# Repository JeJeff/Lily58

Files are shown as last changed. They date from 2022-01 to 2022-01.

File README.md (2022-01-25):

# Lily58
Lily58 is 6*4+4keys column-staggered split keyboard.
Lily58Lite-Pic

## [Document Site Here](https://kata0510.github.io/Lily58-Document/)

# Type

- Lily58 Pro
  - [PCB Data](https://github.com/kata0510/Lily58/tree/master/Pro/PCB)
  - [BuildGuide JP](https://kata0510.github.io/Lily58-Document/Lily58_Pro.html)
  - [BuildGuide EN](https://kata0510.github.io/Lily58-Document/Lily58_Pro_BG_ENG.html)
  - [Shop(Yushakobo)](https://yushakobo.jp/shop/lily58-pro/)
- Lily58 Lite Rev2
  - [BuildGuide(YouTube)](https://www.youtube.com/watch?v=t6HLQvqlsVM)
  - [BuildInfo](https://kata0510.github.io/Lily58-Document/Lily58_Lite_Rev2.html)
  - [Shop(BOOTH)](https://booth.pm/ja/items/1963895)
  - [Shop(Yushakobo)](https://yushakobo.jp/shop/consign_lily58-lite-rev2/)
- Lily58(Old)
  - [PCB Data](https://github.com/kata0510/Lily58/tree/master/pcb)
  - [BuildGuide](https://kata0510.github.io/Lily58-Document/Lily58_BG.html)
- Lily58 Lite Rev1(Old)
  - [PCB Data](https://github.com/kata0510/Lily58/tree/master/pcb)
  - [BuildGuide](https://kata0510.github.io/Lily58-Document/Lily58_Lite_BG.html)

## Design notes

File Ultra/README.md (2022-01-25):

# Lily58 Ultra
Lily58 is 6*4+4keys column-staggered split keyboard.

This fork adds the Lily58 Ultra.  This has through-hole diodes only, and adds MX hotswap sockets, per-key and backlight LEDs, and optional rotary encoder support (replacing one of the thumb keys).  The LED support means it no longer supports choc switches.

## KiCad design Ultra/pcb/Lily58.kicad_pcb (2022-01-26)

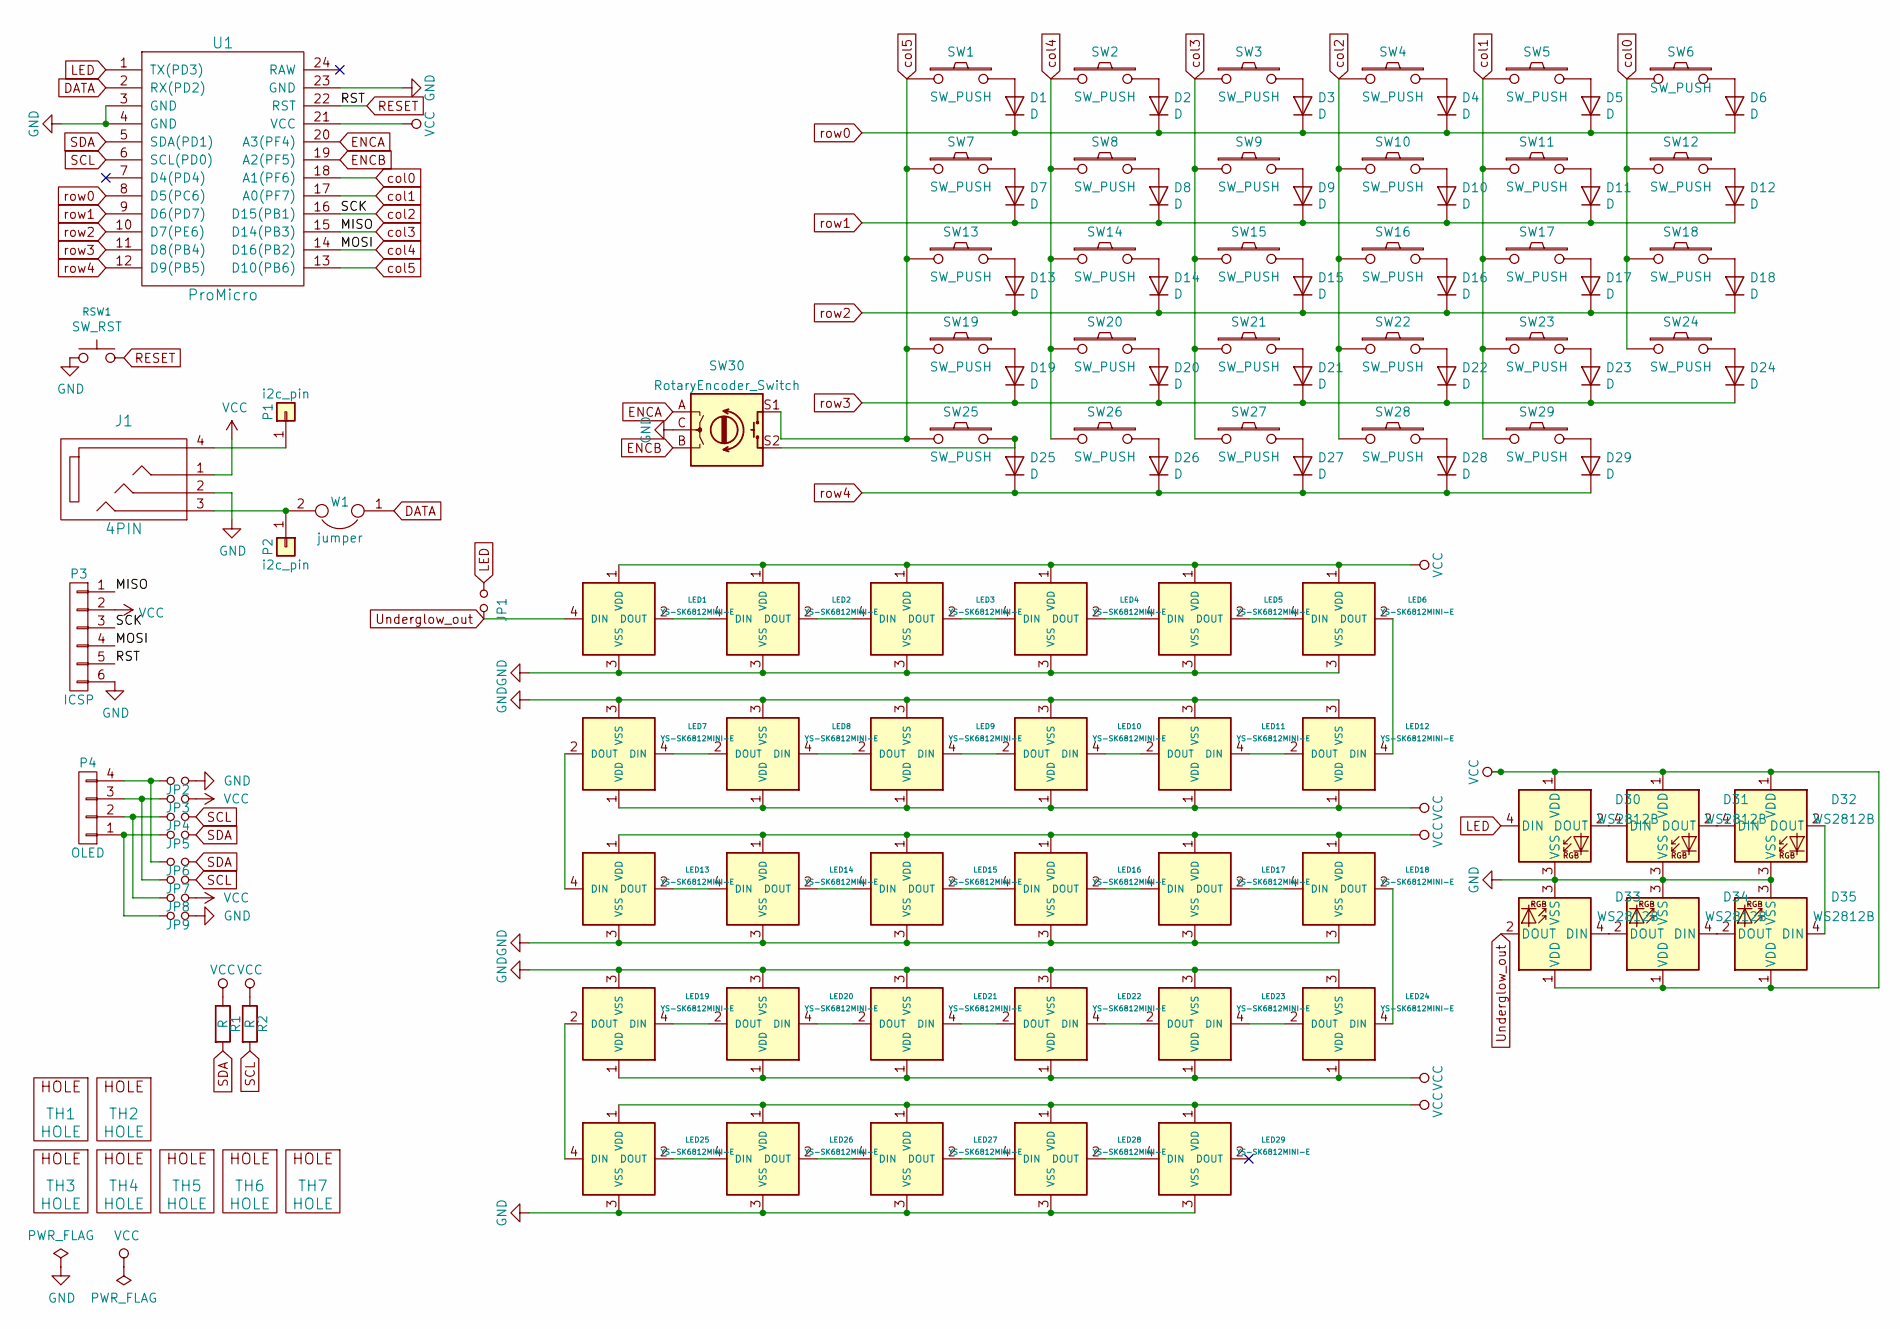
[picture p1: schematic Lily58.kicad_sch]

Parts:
D1, D2, D3, D4, D5, D6, D7, D8, D9, D10, D11, D12, D13, D14, D15, D16, D17, D18, D19, D20, D21, D22, D23, D24, D25, D26, D27, D28, D29: D; Diode-Doublesided-TH-7.5mm
D30, D31, D32, D33, D34, D35: WS2812B; WS2812B-double sided
J1: 4PIN; MJ-4PP-9
JP1, JP2, JP3, JP4, JP5, JP6, JP7, JP8, JP9: Jumper_NO_Small; Jumper
LED1, LED2, LED3, LED4, LED5, LED6, LED7, LED8, LED9, LED10, LED11, LED12, LED13, LED14, LED15, LED16, LED17, LED18, LED19, LED20, LED21, LED22, LED23, LED24, LED25, LED26, LED27, LED28, LED29: YS-SK6812MINI-E; SK6812MINI-E
P1, P2: i2c_pin; 1pin_conn
P3: ICSP
P4: OLED; MY_SIL-4
R1, R2: R; RESISTOR_mini
RSW1: SW_RST; TACT_SWITCH_TVBP06
SW1, SW2, SW3, SW4, SW5, SW6, SW7, SW8, SW9, SW10, SW11, SW12, SW13, SW14, SW15, SW16, SW17, SW18, SW19, SW20, SW21, SW22, SW23, SW24, SW25, SW26, SW27, SW28, SW29: SW_PUSH; MX_Socket_18mm
SW30: RotaryEncoder_Switch; RotaryEncoder_EC11-no-legs_noSS
TH1, TH2: HOLE; HOLE_M2
TH3, TH4, TH5, TH6, TH7: HOLE; HOLE_M2_TH
U1: ProMicro; ProMicro_rev2
W1: jumper; jumper_data

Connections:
DATA: U1.2 (RX(PD2)), W1.1
ENCA: SW30.A, U1.20 (A3(PF4))
ENCB: SW30.B, U1.19 (A2(PF5))
GND: D30.3 (VSS), D31.3 (VSS), D32.3 (VSS), D33.3 (VSS), D34.3 (VSS), D35.3 (VSS), J1.2, JP2.2, JP9.2, LED1.3 (VSS), LED2.3 (VSS), LED3.3 (VSS), LED4.3 (VSS), LED5.3 (VSS), LED6.3 (VSS), LED7.3 (VSS), LED8.3 (VSS), LED9.3 (VSS), LED10.3 (VSS), LED11.3 (VSS), LED12.3 (VSS), LED13.3 (VSS), LED14.3 (VSS), LED15.3 (VSS), LED16.3 (VSS), LED17.3 (VSS), LED18.3 (VSS), LED19.3 (VSS), LED20.3 (VSS), LED21.3 (VSS), LED22.3 (VSS), LED23.3 (VSS), LED24.3 (VSS), LED25.3 (VSS), LED26.3 (VSS), LED27.3 (VSS), LED28.3 (VSS), LED29.3 (VSS), P3.6, RSW1.1, SW30.C, U1.3 (GND), U1.4 (GND), U1.23 (GND)
LED: D30.4 (DIN), JP1.2, U1.1 (TX(PD3))
unnamed: D1.2 (A), SW1.2
unnamed: D2.2 (A), SW2.2
unnamed: D3.2 (A), SW3.2
unnamed: D4.2 (A), SW4.2
unnamed: D5.2 (A), SW5.2
unnamed: D6.2 (A), SW6.2
unnamed: D7.2 (A), SW7.2
unnamed: D8.2 (A), SW8.2
unnamed: D9.2 (A), SW9.2
unnamed: D10.2 (A), SW10.2
unnamed: D11.2 (A), SW11.2
unnamed: D12.2 (A), SW12.2
unnamed: D13.2 (A), SW13.2
unnamed: D14.2 (A), SW14.2
unnamed: D15.2 (A), SW15.2
unnamed: D16.2 (A), SW16.2
unnamed: D17.2 (A), SW17.2
unnamed: D18.2 (A), SW18.2
unnamed: D19.2 (A), SW19.2
unnamed: D20.2 (A), SW20.2
unnamed: D21.2 (A), SW21.2
unnamed: D22.2 (A), SW22.2
unnamed: D23.2 (A), SW23.2
unnamed: D24.2 (A), SW24.2
unnamed: D25.2 (A), SW25.2, SW30.S2
unnamed: D26.2 (A), SW26.2
unnamed: D27.2 (A), SW27.2
unnamed: D28.2 (A), SW28.2
unnamed: D29.2 (A), SW29.2
unnamed: D30.2 (DOUT), D31.4 (DIN)
unnamed: D31.2 (DOUT), D32.4 (DIN)
unnamed: D32.2 (DOUT), D35.4 (DIN)
unnamed: D33.4 (DIN), D34.2 (DOUT)
unnamed: D34.4 (DIN), D35.2 (DOUT)
unnamed: J1.3, P2.1, W1.2
unnamed: J1.4, P1.1
unnamed: JP2.1, JP6.1, P4.4
unnamed: JP3.1, JP7.1, P4.3
unnamed: JP4.1, JP8.1, P4.2
unnamed: JP5.1, JP9.1, P4.1
unnamed: LED1.2 (DOUT), LED2.4 (DIN)
unnamed: LED2.2 (DOUT), LED3.4 (DIN)
unnamed: LED3.2 (DOUT), LED4.4 (DIN)
unnamed: LED4.2 (DOUT), LED5.4 (DIN)
unnamed: LED5.2 (DOUT), LED6.4 (DIN)
unnamed: LED7.4 (DIN), LED8.2 (DOUT)
unnamed: LED8.4 (DIN), LED9.2 (DOUT)
unnamed: LED9.4 (DIN), LED10.2 (DOUT)
unnamed: LED10.4 (DIN), LED11.2 (DOUT)
unnamed: LED11.4 (DIN), LED12.2 (DOUT)
unnamed: LED6.2 (DOUT), LED12.4 (DIN)
unnamed: LED13.2 (DOUT), LED14.4 (DIN)
unnamed: LED7.2 (DOUT), LED13.4 (DIN)
unnamed: LED14.2 (DOUT), LED15.4 (DIN)
unnamed: LED15.2 (DOUT), LED16.4 (DIN)
unnamed: LED16.2 (DOUT), LED17.4 (DIN)
unnamed: LED17.2 (DOUT), LED18.4 (DIN)
unnamed: LED18.2 (DOUT), LED24.4 (DIN)
unnamed: LED19.2 (DOUT), LED25.4 (DIN)
unnamed: LED19.4 (DIN), LED20.2 (DOUT)
unnamed: LED20.4 (DIN), LED21.2 (DOUT)
unnamed: LED21.4 (DIN), LED22.2 (DOUT)
unnamed: LED22.4 (DIN), LED23.2 (DOUT)
unnamed: LED23.4 (DIN), LED24.2 (DOUT)
unnamed: LED25.2 (DOUT), LED26.4 (DIN)
unnamed: LED26.2 (DOUT), LED27.4 (DIN)
unnamed: LED27.2 (DOUT), LED28.4 (DIN)
unnamed: LED28.2 (DOUT), LED29.4 (DIN)
RESET: P3.5, RSW1.2, U1.22 (RST)
SCL: JP4.2, JP7.2, R2.2, U1.6 (SCL(PD0))
SDA: JP5.2, JP6.2, R1.2, U1.5 (SDA(PD1))
Underglow_out: D33.2 (DOUT), JP1.1, LED1.4 (DIN)
VCC: D30.1 (VDD), D31.1 (VDD), D32.1 (VDD), D33.1 (VDD), D34.1 (VDD), D35.1 (VDD), J1.1, JP3.2, JP8.2, LED1.1 (VDD), LED2.1 (VDD), LED3.1 (VDD), LED4.1 (VDD), LED5.1 (VDD), LED6.1 (VDD), LED7.1 (VDD), LED8.1 (VDD), LED9.1 (VDD), LED10.1 (VDD), LED11.1 (VDD), LED12.1 (VDD), LED13.1 (VDD), LED14.1 (VDD), LED15.1 (VDD), LED16.1 (VDD), LED17.1 (VDD), LED18.1 (VDD), LED19.1 (VDD), LED20.1 (VDD), LED21.1 (VDD), LED22.1 (VDD), LED23.1 (VDD), LED24.1 (VDD), LED25.1 (VDD), LED26.1 (VDD), LED27.1 (VDD), LED28.1 (VDD), LED29.1 (VDD), P3.2, R1.1, R2.1, U1.21 (VCC)
col0: SW6.1, SW12.1, SW18.1, SW24.1, U1.18 (A1(PF6))
col1: SW5.1, SW11.1, SW17.1, SW23.1, SW29.1, U1.17 (A0(PF7))
col2: P3.3, SW4.1, SW10.1, SW16.1, SW22.1, SW28.1, U1.16 (D15(PB1))
col3: P3.1, SW3.1, SW9.1, SW15.1, SW21.1, SW27.1, U1.15 (D14(PB3))
col4: P3.4, SW2.1, SW8.1, SW14.1, SW20.1, SW26.1, U1.14 (D16(PB2))
col5: SW1.1, SW7.1, SW13.1, SW19.1, SW25.1, SW30.S1, U1.13 (D10(PB6))
row0: D1.1 (K), D2.1 (K), D3.1 (K), D4.1 (K), D5.1 (K), D6.1 (K), U1.8 (D5(PC6))
row1: D7.1 (K), D8.1 (K), D9.1 (K), D10.1 (K), D11.1 (K), D12.1 (K), U1.9 (D6(PD7))
row2: D13.1 (K), D14.1 (K), D15.1 (K), D16.1 (K), D17.1 (K), D18.1 (K), U1.10 (D7(PE6))
row3: D19.1 (K), D20.1 (K), D21.1 (K), D22.1 (K), D23.1 (K), D24.1 (K), U1.11 (D8(PB4))
row4: D25.1 (K), D26.1 (K), D27.1 (K), D28.1 (K), D29.1 (K), U1.12 (D9(PB5))

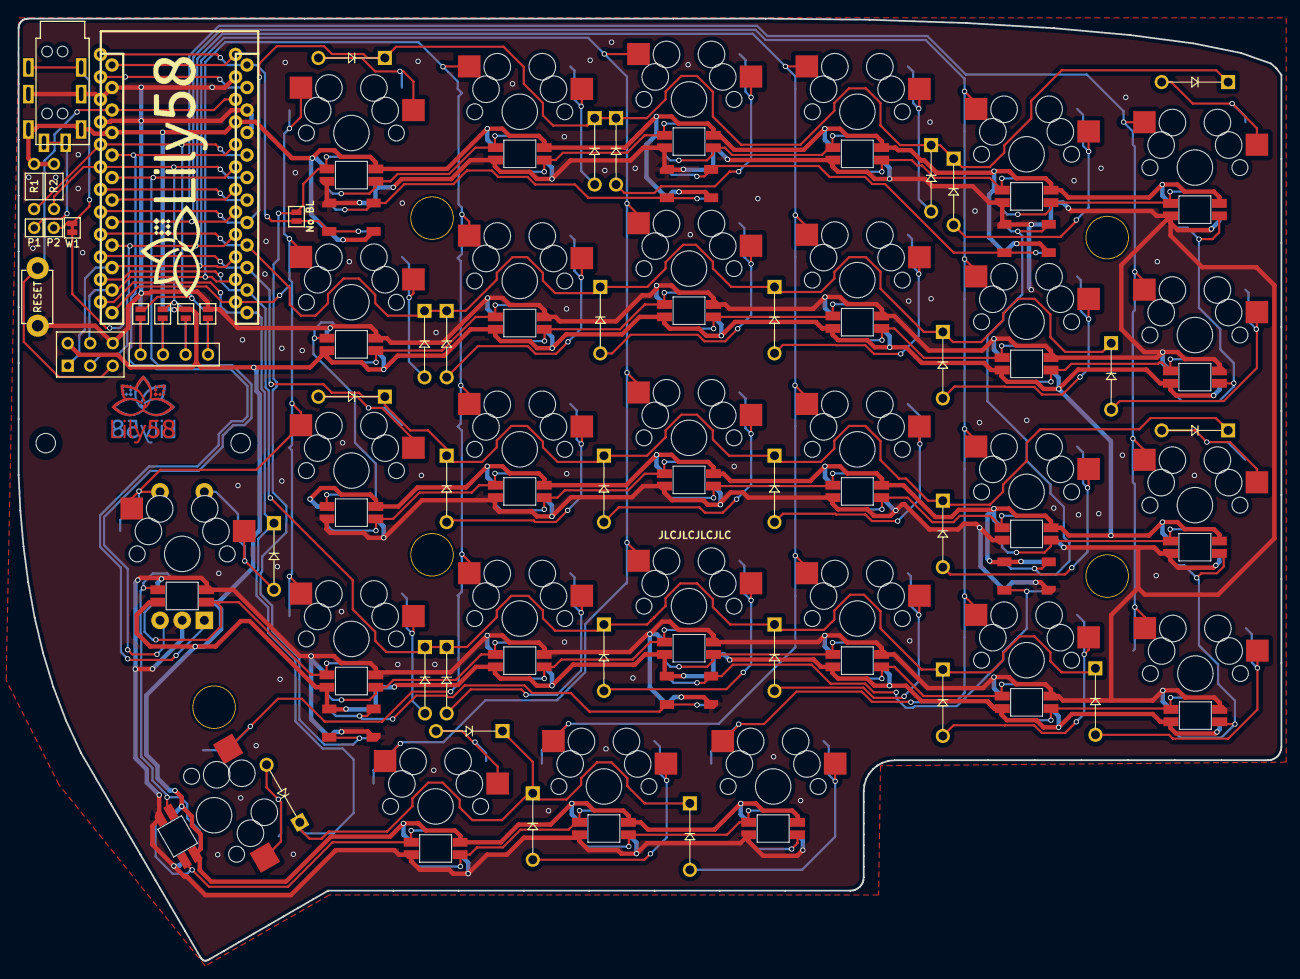
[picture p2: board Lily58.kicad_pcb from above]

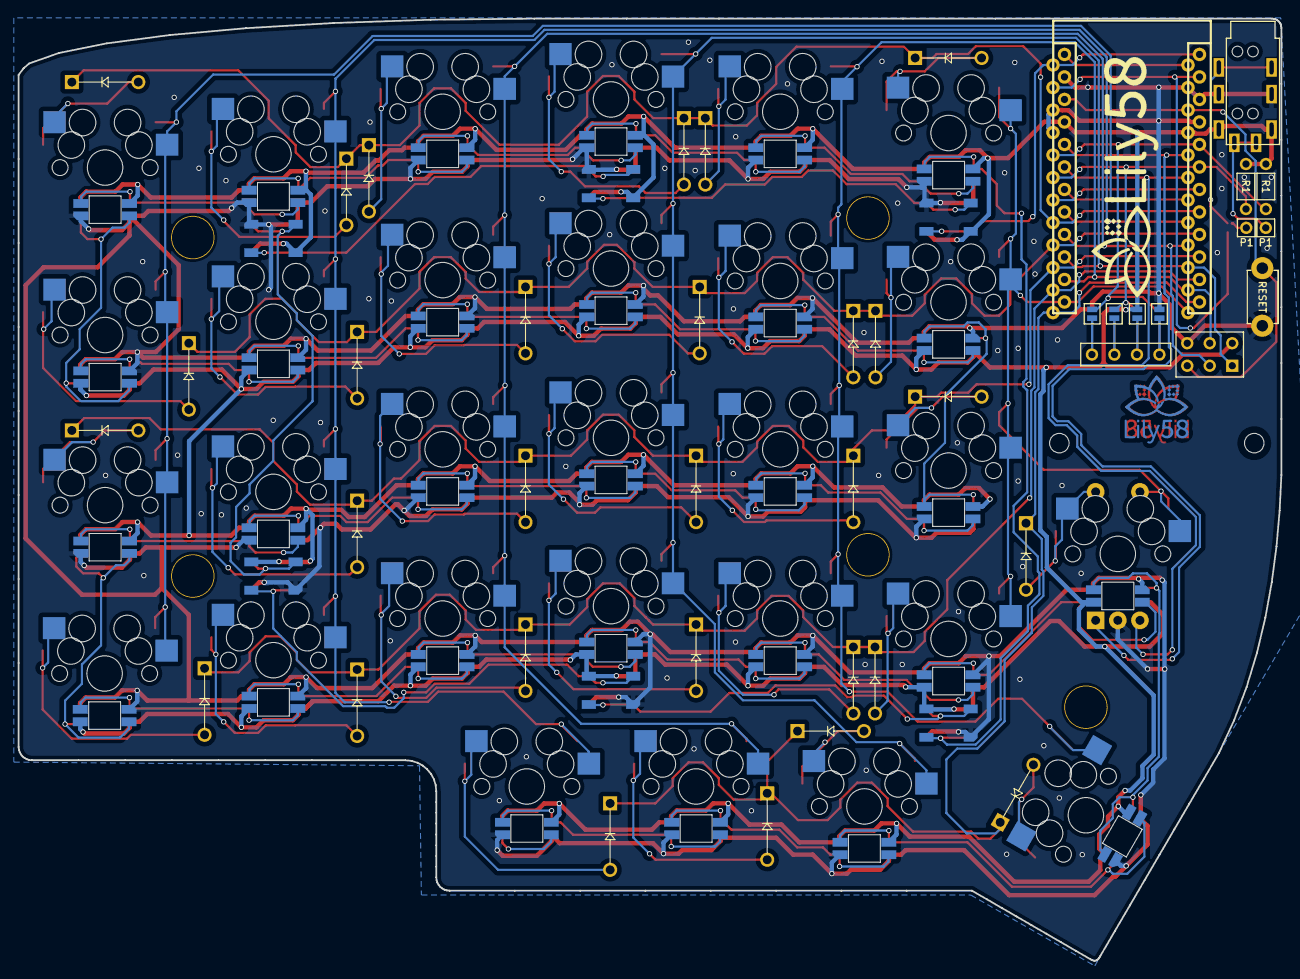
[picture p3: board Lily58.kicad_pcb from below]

Board: 2 copper layers, 142.5 x 106.3 mm, 120 parts (5 on the bottom side), 89 nets.

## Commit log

2022-01-25 First version for prototyping
    [Lily58-B_Cu.gbl, Lily58-B_Mask.gbs, Lily58-B_Silkscreen.gbo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]
2022-01-25 Revert non-ultra changes from "First version for prototyping"
    This partially reverts commit a3e54aa417d9b9a440498bf4f6e0d923b4cb8ab2.
    [Lily58.kicad_pcb, Lily58.kicad_sch]
2022-01-25 Clean up triangle above bottom thumb key
    Cases have trouble covering this, so keep it as bare as possible.
    [Lily58-B_Cu.gbl, Lily58-B_Mask.gbs, Lily58-B_Silkscreen.gbo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]
2022-01-26 Minor routing tweaks
    [Lily58.kicad_pcb]
